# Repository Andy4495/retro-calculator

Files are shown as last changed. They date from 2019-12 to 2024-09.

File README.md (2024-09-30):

# Retro Calculator




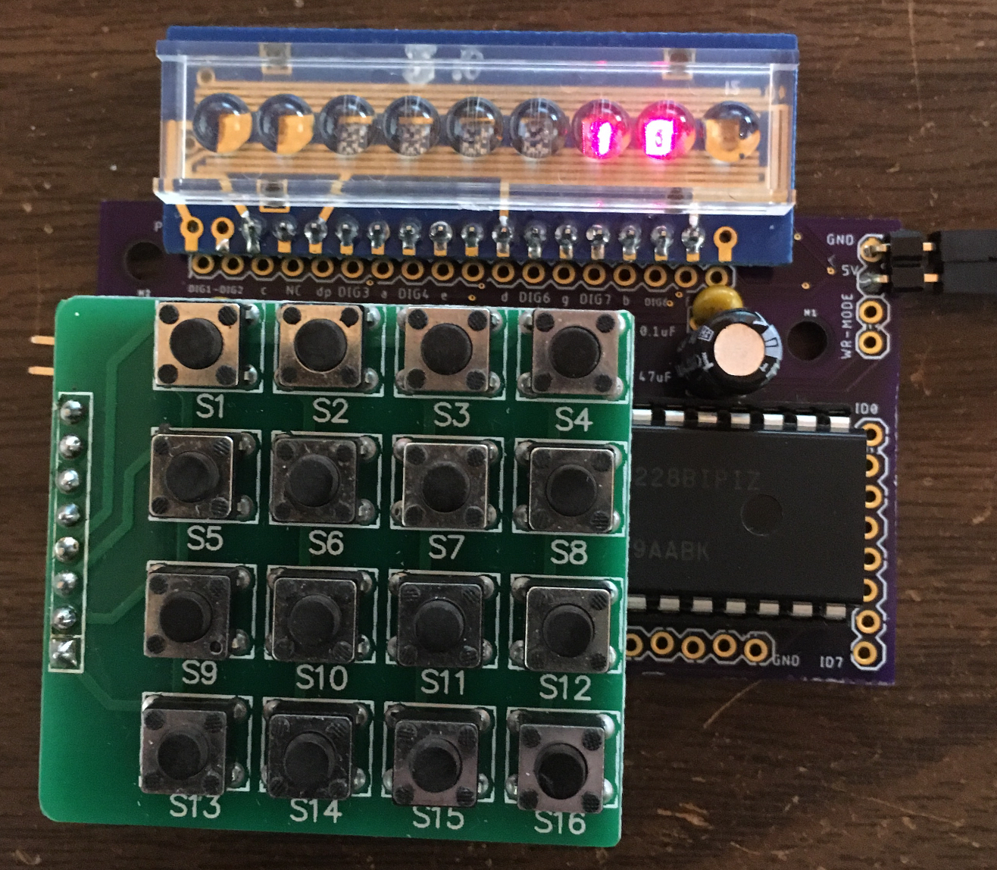
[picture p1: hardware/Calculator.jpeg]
Retro Calculator Image


After seeing an Arduino Project Hub [article][5], I purchased a handful of [NSA1166][2] bubble LED displays from [Jameco][3] and decided to build a [retro calculator][8].

The calculator uses an [MSP430G2553][9] microcontroller and [ICM7228][10] LED driver along with a generic 4x4 matrix keypad.

To make the project as small as possible and to simplify the wiring, I created created a PCB design and ordered it from [OshPark][11].

Due to limitations of my keypad and the display (6 characters with a single fixed decimal point), the calculator only supports limited functions and integer math.

## Hardware

The Eagle BRD and SCH files can be found in the [hardware folder][12], along with a PDF of the [schematic][14].

## External Libraries

The calculator uses my [matrix keypad library][1] and [ICM7218 LED driver library][15].

## References

* Arduino Project Hub [article][5]
* NSA-1166 [datasheet][2]
* NSA-1166 devices at [Jameco][3]
* [MSP430G2553][9]
* [ICM7228][10]
* [Schematic][14]
* [Library][4] written specifically for NSA1166, without using discrete controller IC
* Vintage Novus 650 Mathbox [calculator][6] that used the NSA1166 display, including [interior pictures][7]

## License

The software and other files in this repository are released under what is commonly called the [MIT License][100]. See the file [`LICENSE`][101] in this repository.

[1]: https://github.com/Andy4495/matrix-keypad-library
[2]: https://www.jameco.com/Jameco/Products/ProdDS/2210976NAT.pdf
[3]: https://www.jameco.com/z/NSA1166-National-Semiconductor-LED-Display-7-Segment-Red-0-10-Inch-6-Digit-1-65V-5mA-2-Inch-Long_2210976.html
[4]: https://github.com/8bitkick/SevSegPlus
[5]: https://create.arduino.cc/projecthub/8bitkick/retro-led-bubble-display-d357e9
[6]: https://www.keesvandersanden.nl/calculators/novus650.php
[7]: https://www.keesvandersanden.nl/calculators/novus650_inside.php
[8]: ./hardware/Calculator.jpeg
[9]: https://www.ti.com/product/MSP430G2553
[10]: https://www.renesas.com/us/en/www/doc/datasheet/icm7228.pdf
[11]: https://oshpark.com/
[12]: ./hardware
[14]: ./hardware/retro-calculator-schematic.pdf
[15]: https://github.com/Andy4495/ICM7218
[100]: https://choosealicense.com/licenses/mit/
[101]: ./LICENSE
[//]: # ([200]: https://github.com/Andy4495/retro-calculator)

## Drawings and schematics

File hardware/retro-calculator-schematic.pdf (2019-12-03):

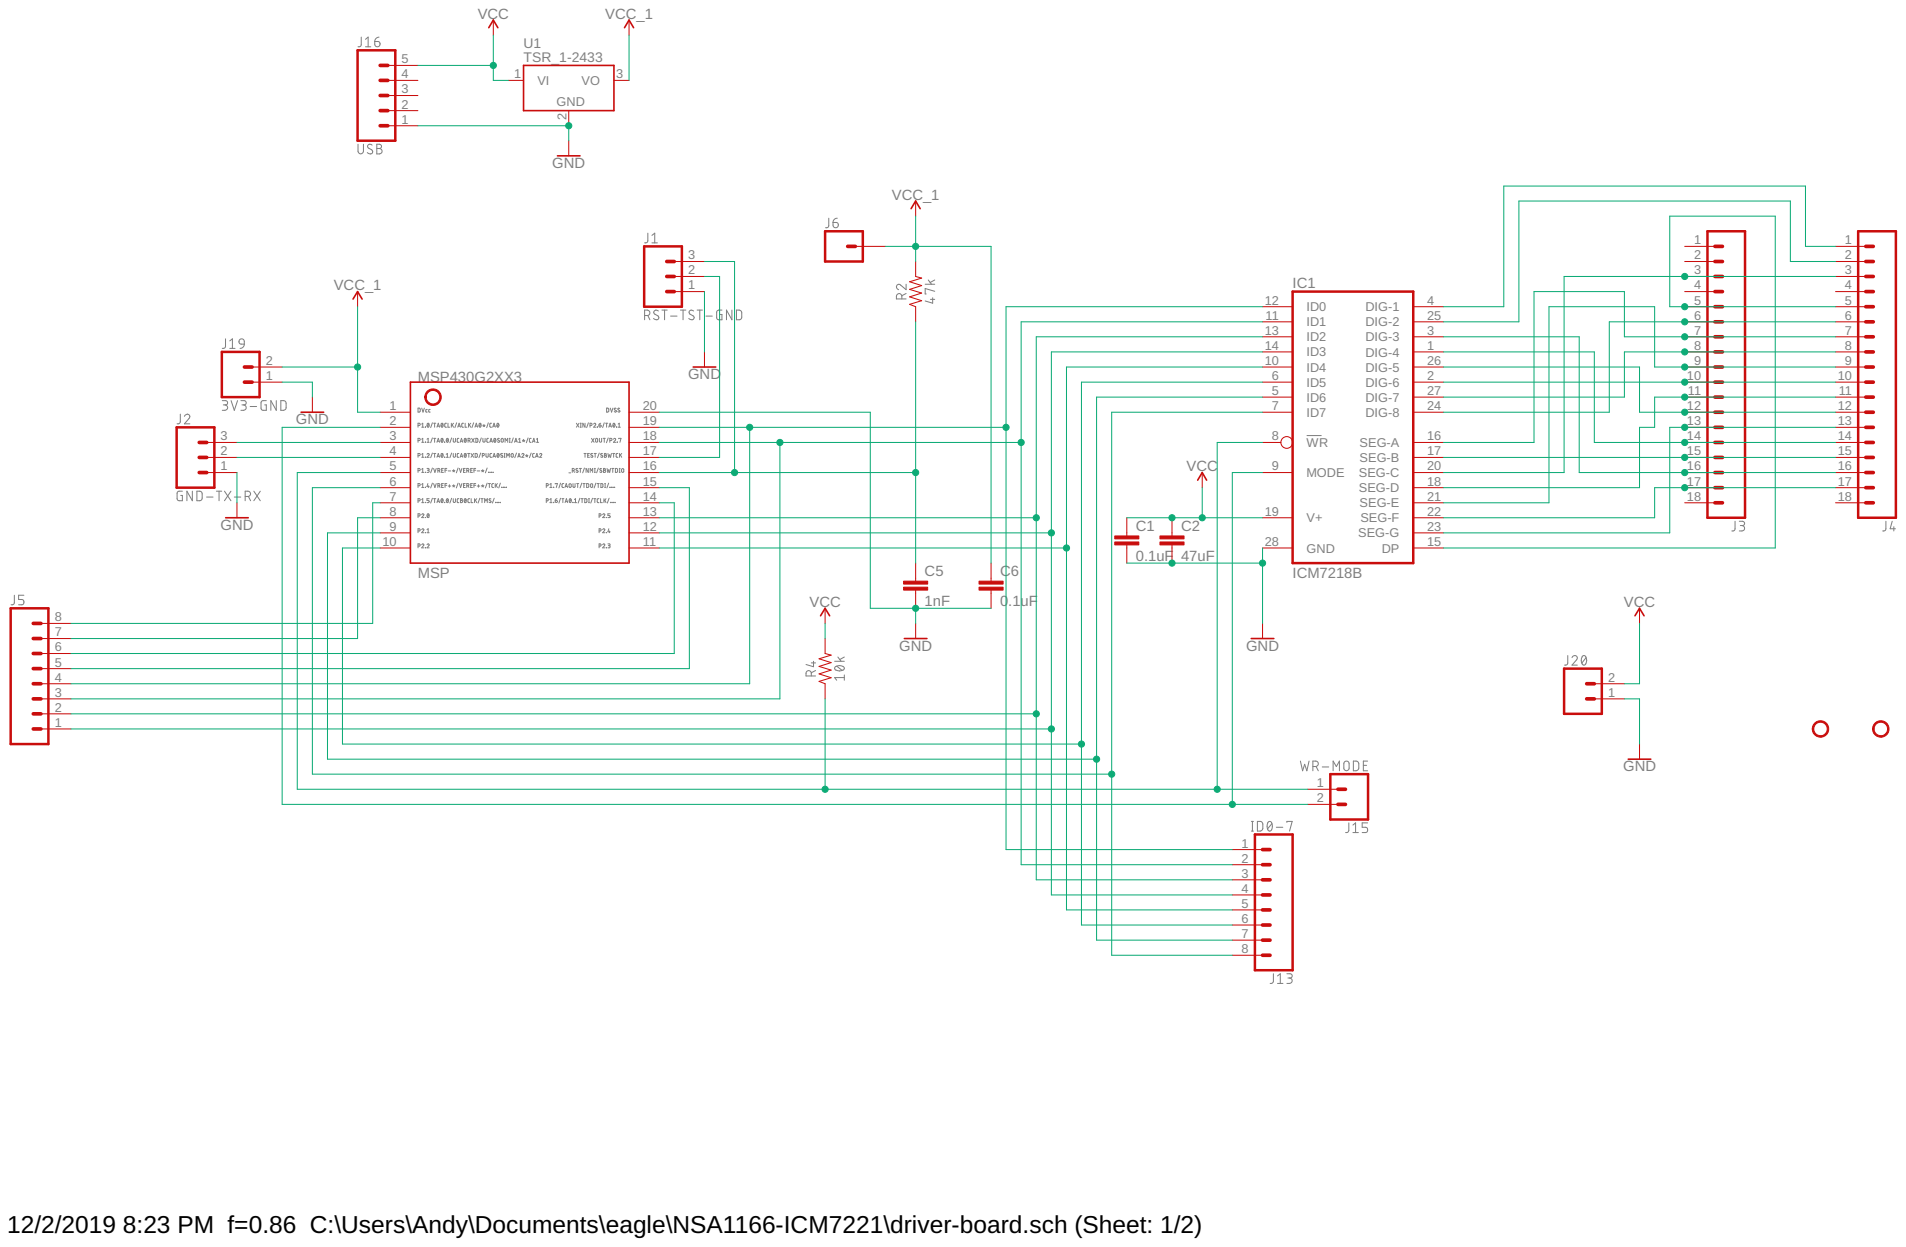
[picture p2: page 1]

11 | 4 DIG-2 25 DIG-3

13 | 3 DIG-4
14 | 1 DIG-5

12/2/2019 8:23 PM f=0.86 C:\Users\Andy\Documents\eagle\NSA1166-ICM7221\driver-board.sch (Sheet: 1/2)

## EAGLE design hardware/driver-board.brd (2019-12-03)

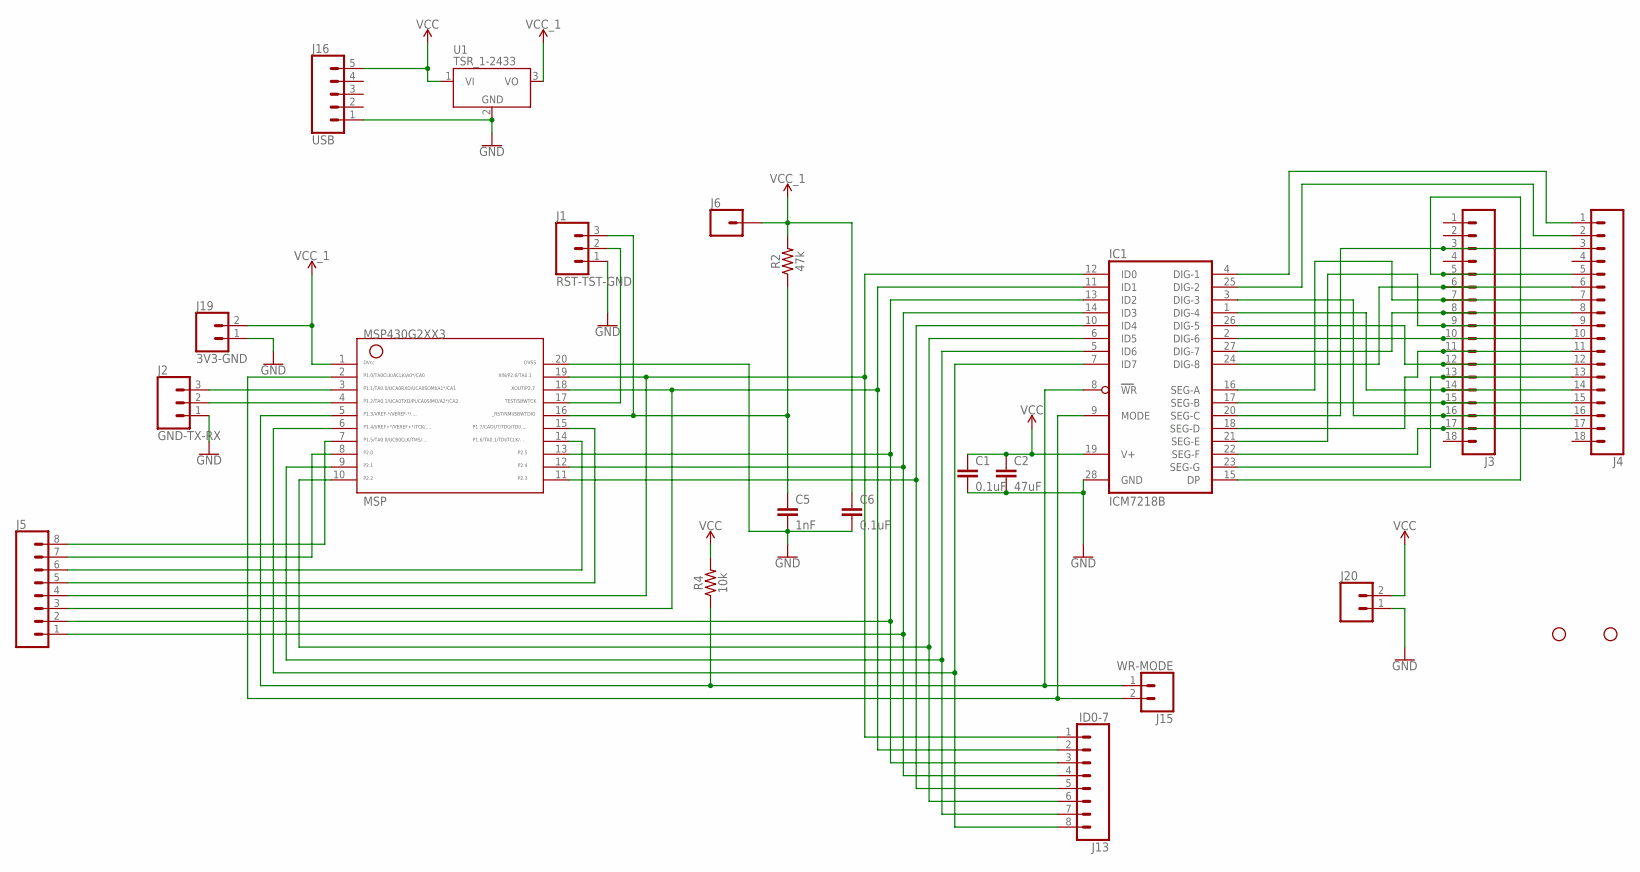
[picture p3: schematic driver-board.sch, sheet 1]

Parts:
C1: 0.1uF; C2.5-2
C2: 47uF; C2.5-5
C5: 1nF; C5B2.5
C6: 0.1uF; C5B2.5
H1, H2: STAND-OFF
IC1: ICM7218B; DIL28-6
J1: RST-TST-GND; 1X03_LOCK
J2: GND-TX-RX; 1X03_LOCK
J3, J4: CONN_18; 1X18
J5: CONN_08"; 1X08
J6: CONN_01; 1X01
J13: ID0-7; 1X08_LOCK
J15: WR-MODE; 1X02
J16: USB; 1X05_LOCK
J19: 3V3-GND; 1X02
J20: CONN_02; 1X02
MSP: G2XX3---N20; N20
R2: 47k; AXIAL-0.3
R4: 10k; AXIAL-0.3
U1: TSR_1-2433; TSR-1

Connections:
GND: C1.2, C2.2, C5.2, C6.2, IC1.28 (GND), J1.1, J2.1, J16.1, J19.1, J20.1, MSP.20, U1.2 (GND)
unnamed: IC1.3 (DIG-3), J3.16, J4.16
unnamed: IC1.1 (DIG-4), J3.14, J4.14
unnamed: IC1.26 (DIG-5), J3.12, J4.12
unnamed: J5.8, MSP.7
unnamed: IC1.2 (DIG-6), J3.10, J4.10
unnamed: IC1.27 (DIG-7), J3.8, J4.8
unnamed: IC1.15 (DP), J3.5, J4.5
unnamed: IC1.23 (SEG-G), J3.13, J4.13
unnamed: IC1.24 (DIG-8), J3.6, J4.6
unnamed: IC1.22 (SEG-F), J3.17, J4.17
unnamed: IC1.20 (SEG-C), J3.3, J4.3
unnamed: J5.7, MSP.8
unnamed: IC1.17 (SEG-B), J3.15, J4.15
unnamed: IC1.18 (SEG-D), J3.11, J4.11
unnamed: IC1.21 (SEG-E), J3.9, J4.9
unnamed: IC1.16 (SEG-A), J3.7, J4.7
unnamed: IC1.25 (DIG-2), J4.2
unnamed: IC1.4 (DIG-1), J4.1
unnamed: J2.2, MSP.4
unnamed: J5.6, MSP.14
unnamed: C5.1, J1.3, MSP.16, R2.P$1 (1)
unnamed: J5.5, MSP.15
unnamed: J1.2, MSP.17
unnamed: IC1.14 (ID3), J5.1, J13.4, MSP.12
unnamed: IC1.10 (ID4), J13.5, MSP.11
unnamed: IC1.12 (ID0), J5.4, J13.1, MSP.19
unnamed: IC1.11 (ID1), J5.3, J13.2, MSP.18
unnamed: IC1.6 (ID5), J13.6, MSP.10
unnamed: IC1.5 (ID6), J13.7, MSP.9
unnamed: IC1.7 (ID7), J13.8, MSP.6
unnamed: IC1.8 (WR), J15.1, MSP.5, R4.P$1 (1)
unnamed: IC1.9 (MODE), J15.2, MSP.2
unnamed: J2.3, MSP.3
unnamed: IC1.13 (ID2), J5.2, J13.3, MSP.13
VCC: C1.1, C2.1, IC1.19 (V+), J16.5, J20.2, R4.P$2 (2), U1.1 (VI)
VCC_1: C6.1, J6.1, J19.2, MSP.1, R2.P$2 (2), U1.3 (VO)

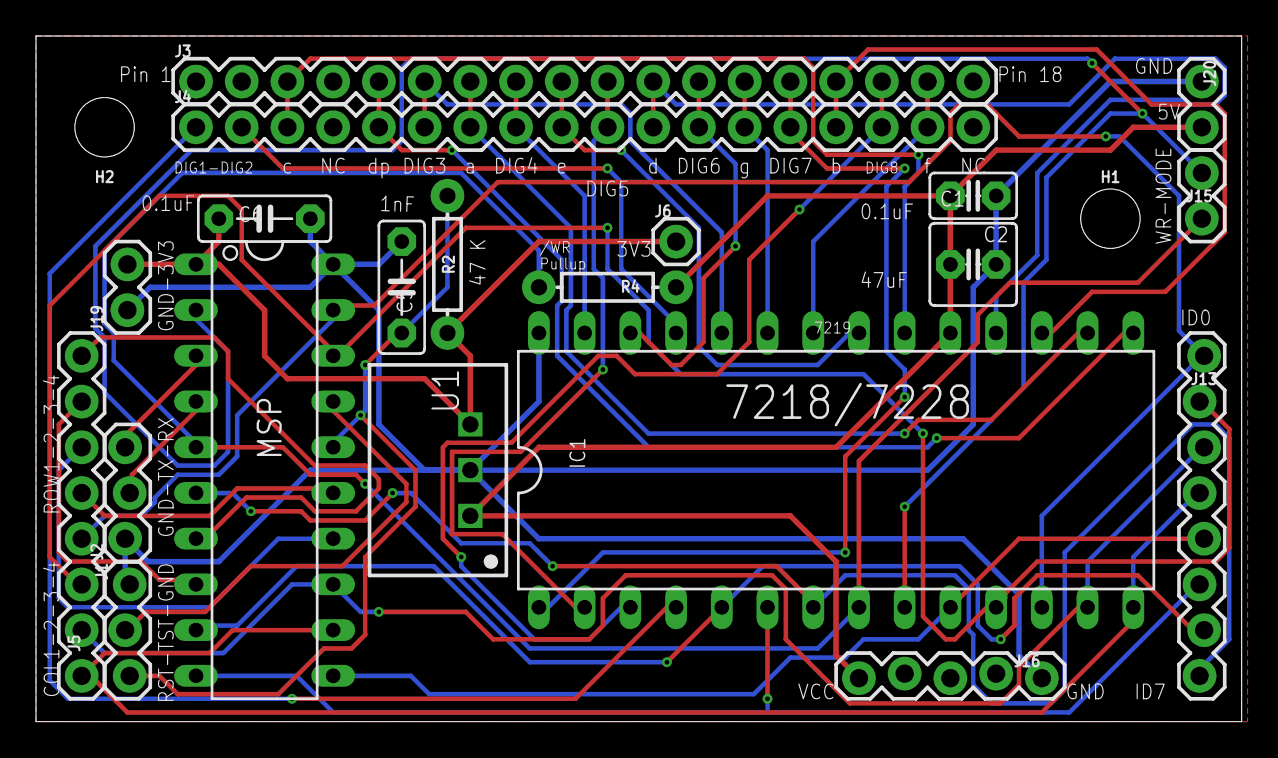
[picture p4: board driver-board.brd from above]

Board: 2 copper layers, 67.0 x 38.1 mm, 22 parts (0 on the bottom side), 37 nets.

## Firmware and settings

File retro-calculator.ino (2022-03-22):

// Retro calculator using NSA 1166 Bubble Display and ICM7218 LED driver
// Note that the NSA1166 display only has 6 digits and a single fixed
// decimal point. 
//
// https://github.com/Andy4495/retro-calculator
//
// 1.0.0    04/12/2019  A.T.   Original
// 1.1.0    12/06/2019  A.T.   Use debounce routines from updated keypad library. 


#include <ICM7218.h>
#include <Keypad4495.h>

// Create a keypad object
#define NUM_ROWS 4
#define NUM_COLS 4
byte rowPins[NUM_ROWS] = {15, 14, 8, 7};
byte colPins[NUM_COLS] = {19, 18, 13, 12};
char keymap[NUM_COLS * NUM_ROWS] = { '1', '2', '3', '+', '4', '5', '6', '-', '7', '8', '9', '*', 'C', '0', '=', '/' };
Keypad4495 myKeypad(keymap, rowPins, colPins, NUM_ROWS, NUM_COLS, true);

// Configure the 10 OUTPUT pins used to interface with ICM7218: D0-D7, mode, write
ICM7218 myLED(19, 18, 13, 12, 11, 10, 9, 6, 2, 5);

// NSA1166 is a 6 digit display
#define MAXCHARS 6

// Debounce time in ms. Normally 20 ms is sufficient for most types of buttons
#define DEBOUNCE_TIME 20

enum STATE {ENTRY1, ENTRY2, EQUALS, ERROR};

enum OPERATOR {NONE, PLUS, MINUS, MULT, DIV};

char convertBuffer[MAXCHARS + 1];
char entryString[MAXCHARS + 1];
char c;
int i = 0;
long op1, op2;
STATE    state = ENTRY1;
OPERATOR op    = NONE;
int pos = 5; // Position of current digit in entryString, right justify, leave a space for terminator


void setup() {
  // Use DIRECT mode since we will display some special characters
  myLED.setMode(ICM7218::DIRECT);

  memset(entryString, 0, MAXCHARS + 1); // clear the entry string
  displayCalc();
}

void loop() {
  long answer;

  // Debounce: Waits for button to be released before returning
  c = myKeypad.getKeyWithDebounce();

  switch (c) {
    case Keypad4495::NO_KEY:
      // Do nothing and loop around and check again
      break;

    case '0':
    case '1':
    case '2':
    case '3':
    case '4':
    case '5':
    case '6':
    case '7':
    case '8':
    case '9':
      // Add to char array to max of 6 digits
      // Drop MSB as more digits entered
      if (i >= MAXCHARS) {
        for (i = 1; i < MAXCHARS; i++) {
          entryString[i - 1] = entryString[i];
        }
        i = 5;
      }
      entryString[i] = c;
      i++;
      convertToDisplayFormat(entryString);
      myLED.print(convertBuffer);
      break;

    case '+':
      // Set operation as plus
      // Set state as entry2
      // Save first value string to number
      // Clear out entry string
      state = ENTRY2;
      op = PLUS;
      op1 = atol(entryString);
      memset(entryString, 0, MAXCHARS + 1); // clear the entry string
      i = 0;
      sprintf(convertBuffer, "  Plus");
      myLED.convertToSegments(convertBuffer);
      myLED.print(convertBuffer);
      break;

    case '-':
      // Set operation as "subtraction"
      // Save first value string to number
      // Set state as entry2
      // Clear out entry string
      state = ENTRY2;
      op = MINUS;
      op1 = atol(entryString);
      memset(entryString, 0, MAXCHARS + 1); // clear the entry string
      i = 0;
      sprintf(convertBuffer, " Subtr");
      myLED.convertToSegments(convertBuffer);
      myLED.print(convertBuffer);
      break;

    case '*':
      // Set operation as "mult"
      // Save first value string to number
      // Set state as entry2
      // Clear out entry string
      state = ENTRY2;
      op = MULT;
      op1 = atol(entryString);
      memset(entryString, 0, MAXCHARS + 1); // clear the entry string
      i = 0;
      sprintf(convertBuffer, "  Prod");
      myLED.convertToSegments(convertBuffer);
      myLED.print(convertBuffer);
      break;

    case '/':
      // Set operation as "div"
      // Save first value string to number
      // Set state as entry2
      // Clear out entry string
      state = ENTRY2;
      op = DIV;
      op1 = atol(entryString);
      memset(entryString, 0, MAXCHARS + 1); // clear the entry string
      i = 0;
      sprintf(convertBuffer, "   Div");
      myLED.convertToSegments(convertBuffer);
      myLED.print(convertBuffer);
      break;

    case 'C':
      // Clear entry string and display zero
      memset(entryString, 0, 7); // clear the entry string
      i = 0;
      convertBuffer[MAXCHARS - 1] = c;
      memset(convertBuffer, ' ', MAXCHARS - 2);
      convertBuffer[MAXCHARS] = 0;
      myLED.convertToSegments(convertBuffer);
      myLED.print(convertBuffer);
      break;

    case '=':
      // Check for overflow, display error if needed
      //
      state = ENTRY1;
      op2 = atol(entryString);
      i = 0;
      switch (op) {
        case PLUS:
          answer = op1 + op2;
          if ((answer > 999999) || (answer < -99999)) state = ERROR;
          break;

        case MINUS:
          answer = op1 - op2;
          if ((answer > 999999) || (answer < -99999)) state = ERROR;
          break;

        case MULT:
          answer = op1 * op2;
          if ((answer > 999999) || (answer < -99999)) state = ERROR;
          break;

        case DIV:
          if (op2 == 0) state = ERROR;
          else answer = op1 / op2;
          if ((answer > 999999) || (answer < -99999)) state = ERROR;
          break;

        default:
          state = ERROR;
          break;
      }
      if (state != ERROR) {
        snprintf(entryString, MAXCHARS + 1, "%6ld", answer);
        convertToDisplayFormat(entryString);
        myLED.print(convertBuffer);
      } else {
        displayError();
        state = ENTRY1;
      }
      memset(entryString, 0, MAXCHARS + 1); // clear the entry string
      break;

    default:
      displayError();
      memset(entryString, 0, MAXCHARS + 1); // clear the entry string
      state = ENTRY1;
      break;

  }
}

void displayError() {
  snprintf(convertBuffer, MAXCHARS + 1, "Error");
  myLED.convertToSegments(convertBuffer);
  myLED.print(convertBuffer);
}

void displayCalc() {
  snprintf(convertBuffer, MAXCHARS + 1, " CALC ");
  myLED.convertToSegments(convertBuffer);
  myLED.print(convertBuffer);
}

void convertToDisplayFormat(char* rawString) {
  int j;

  sprintf(convertBuffer, "%6ld", atol(rawString));

  convertBuffer[MAXCHARS] = 0;    // Add NULL terminator
  myLED.convertToSegments(convertBuffer);
}

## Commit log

2019-12-03 Add readme, schematic, eagle files, photo.
    [driver-board.brd, driver-board.sch]
2022-06-18 Load board manager URL from GitHub
2024-09-30 Switch to lychee for link checks

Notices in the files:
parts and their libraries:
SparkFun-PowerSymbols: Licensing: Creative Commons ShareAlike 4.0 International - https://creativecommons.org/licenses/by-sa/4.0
